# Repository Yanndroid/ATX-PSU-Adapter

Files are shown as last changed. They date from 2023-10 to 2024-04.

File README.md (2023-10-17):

# ATX PSU Adapter

This simple breakout board for a 24-pin ATX power supply provides 12V, 5V, 3.3V, and standby 5V. Additionally, it also has a small circuit to control the PSU.

Personally, I'm using this PCB to power my Raspberry Pi via the standby 5V line and can automatically turn the PSU on or off for other devices that also draw power from the PSU.

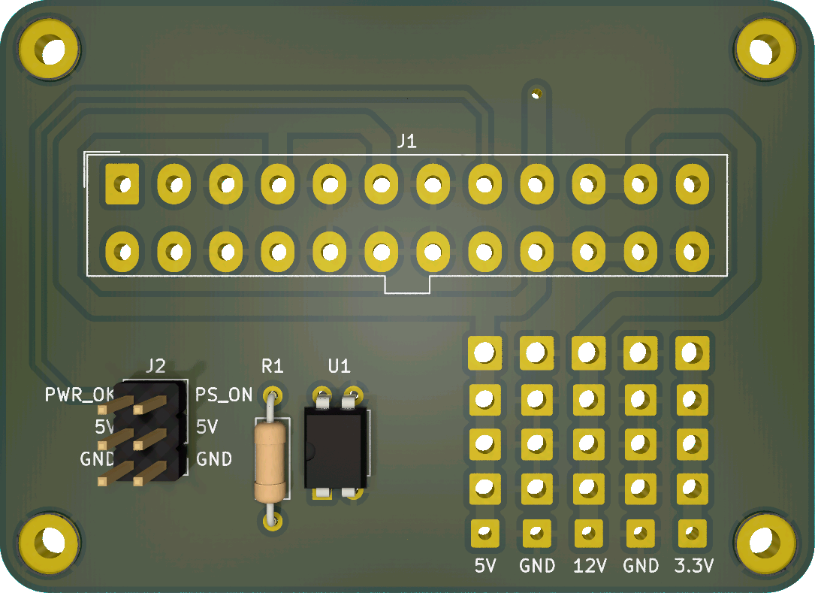
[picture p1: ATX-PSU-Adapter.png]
image description


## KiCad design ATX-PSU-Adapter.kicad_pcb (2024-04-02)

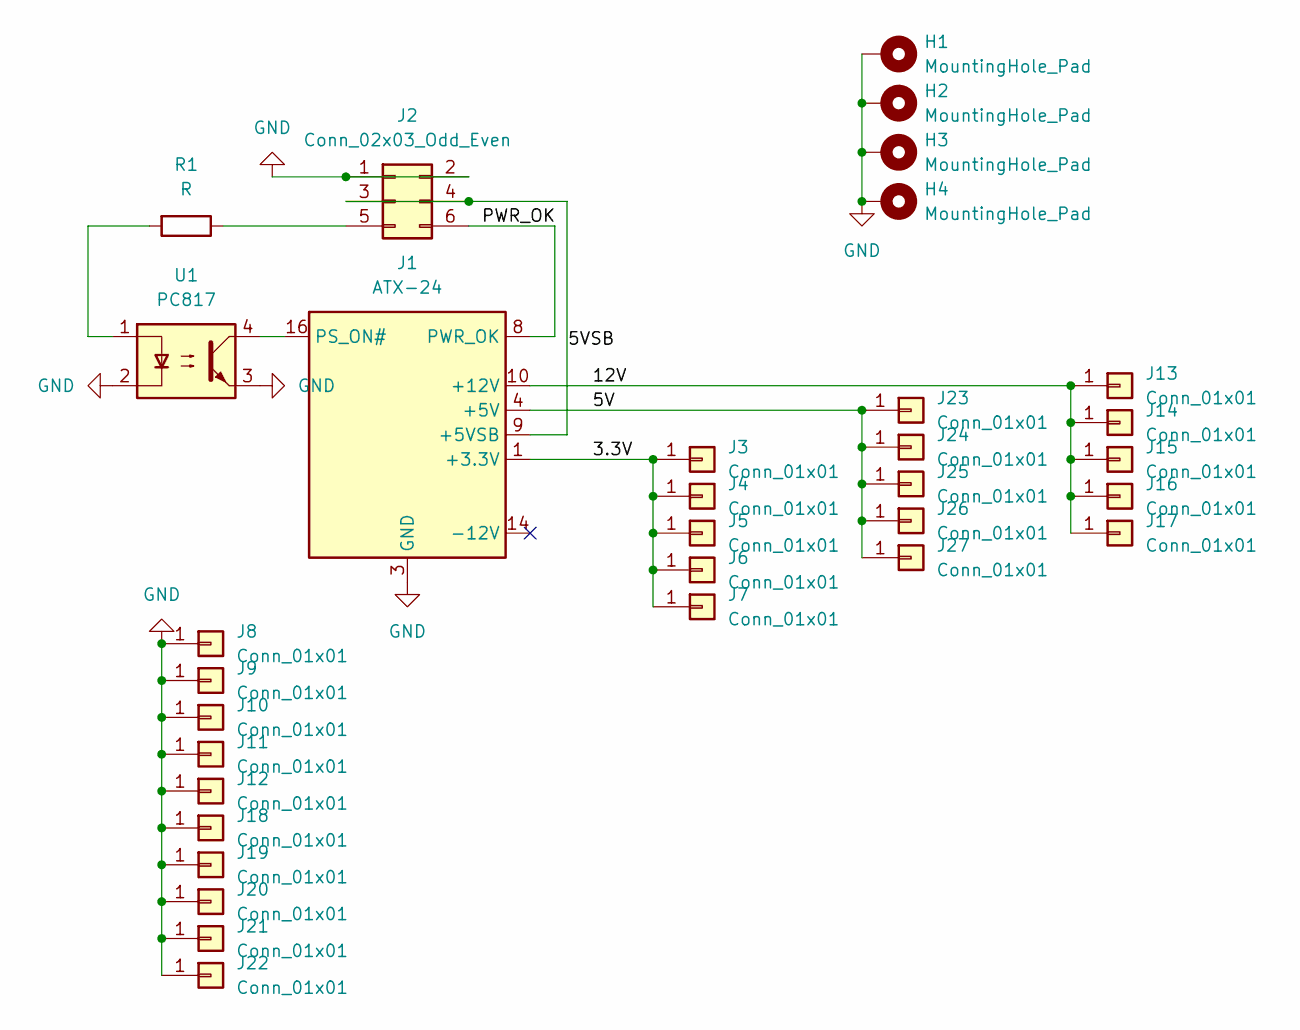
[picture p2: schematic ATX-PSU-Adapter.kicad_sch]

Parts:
H1, H2, H3, H4: MountingHole_Pad; MountingHole_2.5mm_Pad
J1: ATX-24; Molex_Mini-Fit_Jr_5566-24A_2x12_P4.20mm_Vertical
J2: Conn_02x03_Odd_Even; PinHeader_2x03_P2.54mm_Vertical
J3, J8, J13, J18, J23: Conn_01x01; SolderWire-0.5sqmm_1x01_D0.9mm_OD2.3mm
J4, J5, J6, J9, J10, J11, J14, J15, J16, J19, J20, J21, J24, J25, J26: Conn_01x01; SolderWire-0.75sqmm_1x01_D1.25mm_OD2.3mm
J7, J12, J17, J22, J27: Conn_01x01; SolderWire-1sqmm_1x01_D1.4mm_OD2.7mm
R1: R; R_Axial_DIN0207_L6.3mm_D2.5mm_P10.16mm_Horizontal
U1: PC817; DIP-4_W7.62mm

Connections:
/3.3V: J1.1 (+3.3V), J1.2 (+3.3V), J1.12 (+3.3V), J1.13 (+3.3V), J3.1, J4.1, J5.1, J6.1, J7.1
/5V: J1.4 (+5V), J1.6 (+5V), J1.21 (+5V), J1.22 (+5V), J1.23 (+5V), J23.1, J24.1, J25.1, J26.1, J27.1
/5VSB: J1.9 (+5VSB), J2.3, J2.4
/12V: J1.10 (+12V), J1.11 (+12V), J13.1, J14.1, J15.1, J16.1, J17.1
/PWR_OK: J1.8 (PWR_OK), J2.6
GND: H1.1, H2.1, H3.1, H4.1, J1.3 (GND), J1.5 (GND), J1.7 (GND), J1.15 (GND), J1.17 (GND), J1.18 (GND), J1.19 (GND), J1.24 (GND), J2.1, J2.2, J8.1, J9.1, J10.1, J11.1, J12.1, J18.1, J19.1, J20.1, J21.1, J22.1, U1.2, U1.3
unnamed: J1.16 (PS_ON#), U1.4
unnamed: J2.5, R1.1
unnamed: R1.2, U1.1

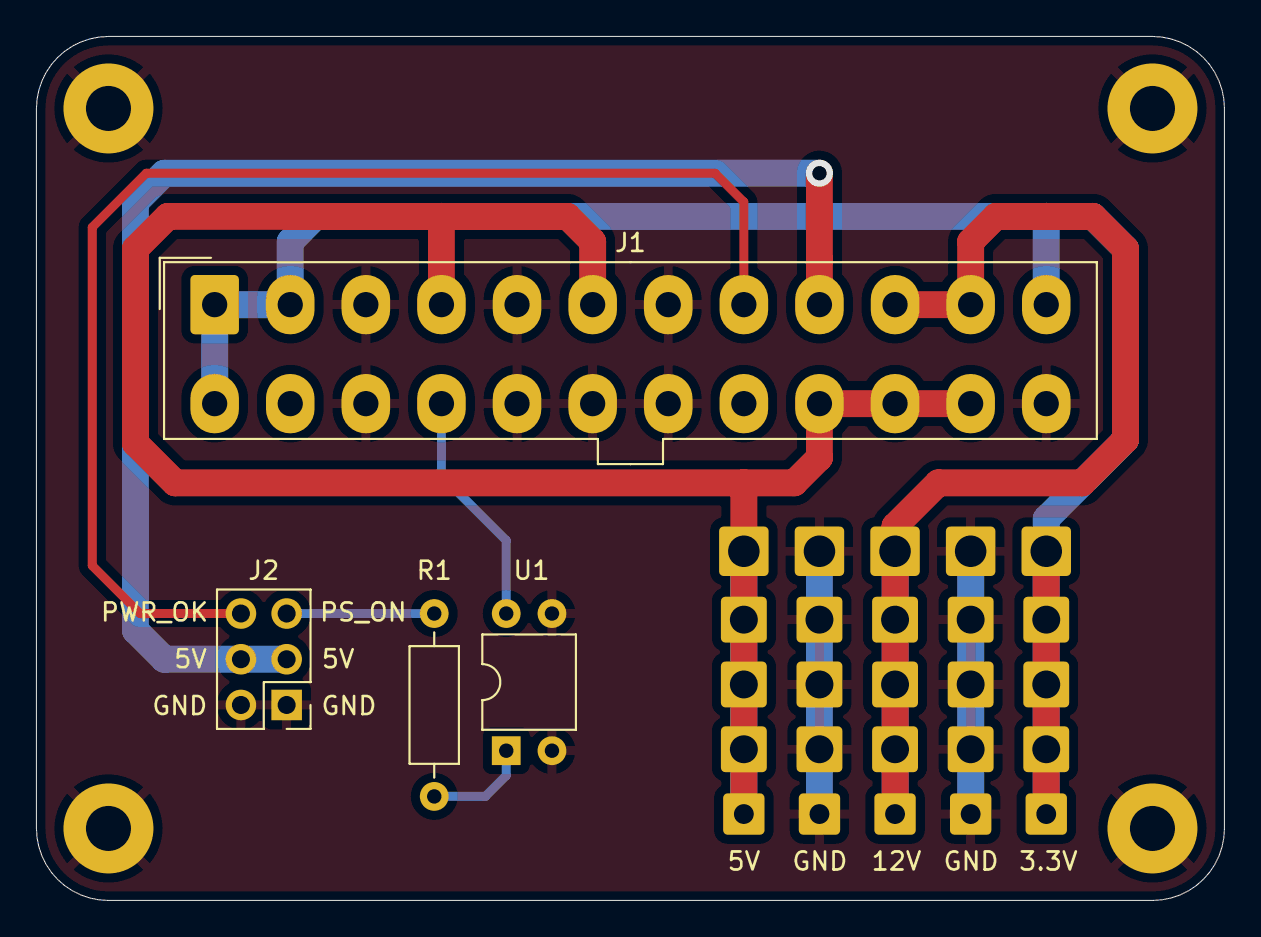
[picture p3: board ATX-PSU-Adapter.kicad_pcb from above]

Board: 2 copper layers, 66.0 x 48.0 mm, 33 parts (0 on the bottom side), 9 nets.

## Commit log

2023-09-23 Replace ATX Connector
    [ATX-PSU-Adapter.kicad_pcb, ATX-PSU-Adapter.kicad_sch]
2023-09-23 Replace pinheader
    [ATX-PSU-Adapter.kicad_pcb, ATX-PSU-Adapter.kicad_sch]
2023-09-23 Adjust text
    [ATX-PSU-Adapter.kicad_pcb]
2023-09-23 Switch 5VSB and GND
    [ATX-PSU-Adapter.kicad_pcb, ATX-PSU-Adapter.kicad_sch]
2023-09-23 Production files
    [BOM-ATX-PSU-Adapter.csv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]
2023-10-17 Fix: ATX Connector Footprint, Optocoupler wiring
    [ATX-PSU-Adapter.kicad_pcb, ATX-PSU-Adapter.kicad_sch]
2024-04-02 Replace ATX connector, wiring and layout
    [ATX-PSU-Adapter.kicad_pcb, ATX-PSU-Adapter.kicad_sch, BOM-ATX-PSU-Adapter.csv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]
